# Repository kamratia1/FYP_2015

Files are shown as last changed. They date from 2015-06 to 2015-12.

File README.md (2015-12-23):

# Control of a MEMS Scanning Mirror for Display Applications
Imperial College London. Electrical and Electronic Engineering. 
Final Year Project. Kishan Amratia

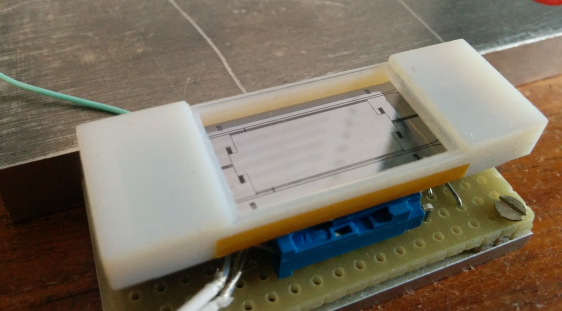
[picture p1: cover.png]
MEMS Scanning Mirror


The repository is split into different folders: 

* __MATLAB Files__: Contains all MATLAB scripts and files for the simulation model developed for the project
* __Microcontroller Files__: Contains software for the microcontroller
* __PCB Design Files__: Contains the EAGLE PCB designs and circuit schematics
* __PICOCAP Documents and Config__: Contains the software, documents and configuration files for the PICOCAP capacitance sensor chip
* __Video__: Contains slow motion video capture of the mirror (400fps)

Additional information on how to use these files is provided in the appendix of the final report

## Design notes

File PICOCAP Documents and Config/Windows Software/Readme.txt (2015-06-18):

INSTALLATION - README:
========================

1. Please do not connect the PicoProg programmer to the PC before asked by the software

2. Run setup.exe from the PCap02plus_Evaluation_and_Assembler

3. Step 2 usually installs the driver for the PicoProg. Only if this fails, please perform setup.exe from the Driver folder.

acam, 06.Feb.2014

========================
The lastest software can be donwloaded from:
http://www.acam.de/download-center/picocap/

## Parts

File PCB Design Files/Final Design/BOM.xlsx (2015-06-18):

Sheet: Digital
Part | Part Number | Description | Manufacturer | Supplier | Order Code | Qty | Unit Price (£)
U5 | STM32F030F4P6TR | ARM Cortex M0 Microcontroller | ST Microelectronics | Farnell | 2432084 | 1 | 0.878
J2, J3 | 22-28-4036 | 3 way 2.54mm pitch Header | MOLEX | Farnell | 1444318 | 2 | 0.06
J1, J4 | M52-040023V0545 | 1.27mm Pitch Stacking Board Connectors Header | HARWIN | Farnell | 1099560 | 2 | 0.406
X1, X2 | XF2M10151A | 10Way FPC Connector 0.5mm Pitch | OMRON | Farnell | 1112555 | 2 | 0.563
U4 | PCAP02AE | PICOCAP2 Digital Capacitance Sensor Chip | ACAM Messelectronic gmbh | SSL2001 | PCAP02AE | 1 | 8.64
U6 | MCP601T-I/OT | General Purpose Single Op-Amp | MICROCHIP | Farnell | 9758631 | 1 | 0.345

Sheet: Voltage Converter
Part | Part Number | Description | Manufacturer | Supplier | Order Code | Qty | Unit Price (£)
M1, M2 | BSS131 | N-Channel MOSFET, 100mA, 240V | Infineon | Farnell | 1056524 | 2 | 0.06
M5, M4 | IRLML2246TRPBF | P-Channel MOSFET, 2.6A, 20V | International Rectifier | Farnell | 1888166 | 2 | 0.0988
U1 | LT3468ES5 | Photoflash Cap Charger | Linear Technology | Farnell | 1663829 | 1 | 3.86
U3 | LM3480IM3-3.3/NOPB | Linear Regulator 3.3V, 100mA | Texas Instruments | Farnell | 1469102 | 1 | 1.2
T1 | CJ5143-ALB | Flyback Transformer 1:15, 15uH | Coilcraft | Farnell | 2458036 | 1 | 2.82
D3, D2 | B0540WS-7 | Schottky Rectifier 40V, 0.5A | Diodes Incorporated | Farnell | 1773477 | 2 | 0.2
D1 | MMBD3004S-7-F | 350V, 0.35W Series Diode Array (Min Order 25) | Diodes Incorporated | RS | 751-4492 | 1 | 0.12
C7, C10, C9, C11 | CGA9P3X7S2A156M250KB | SMD 2220 Package Ceramic Capacitor 100V, 15uF | TDK | Farnell | 2435508 | 4 | 1.3
U2 | LT1006S8 | Low Noise Operational Amplifier | Linear Technology | Farnell | 9559230 | 1 | 3.12
U7 | MCP601T-I/OT | General Purpose Single Op-Amp | MICROCHIP | Farnell | 9758631 | 1 | 0.345
J1, J2 | M52-5000545 | 1.27mm Pitch Stacking Board Connectors Socket | HARWIN | Farnell | 1099543 | 2 | 0.395
X1 | 353630260 | 2Way Right Angle Power Input Connector | MOLEX | Farnell | 9289437 | 1 | 0.0894
 | 355070200 | 2Way Power Input Connector Socket | MOLEX | Farnell | 7571550 | 1 | 0.0751
 | 502128100 | Molex Crimp | MOLEX | Farnell | 7571640 | 2 | 0.101

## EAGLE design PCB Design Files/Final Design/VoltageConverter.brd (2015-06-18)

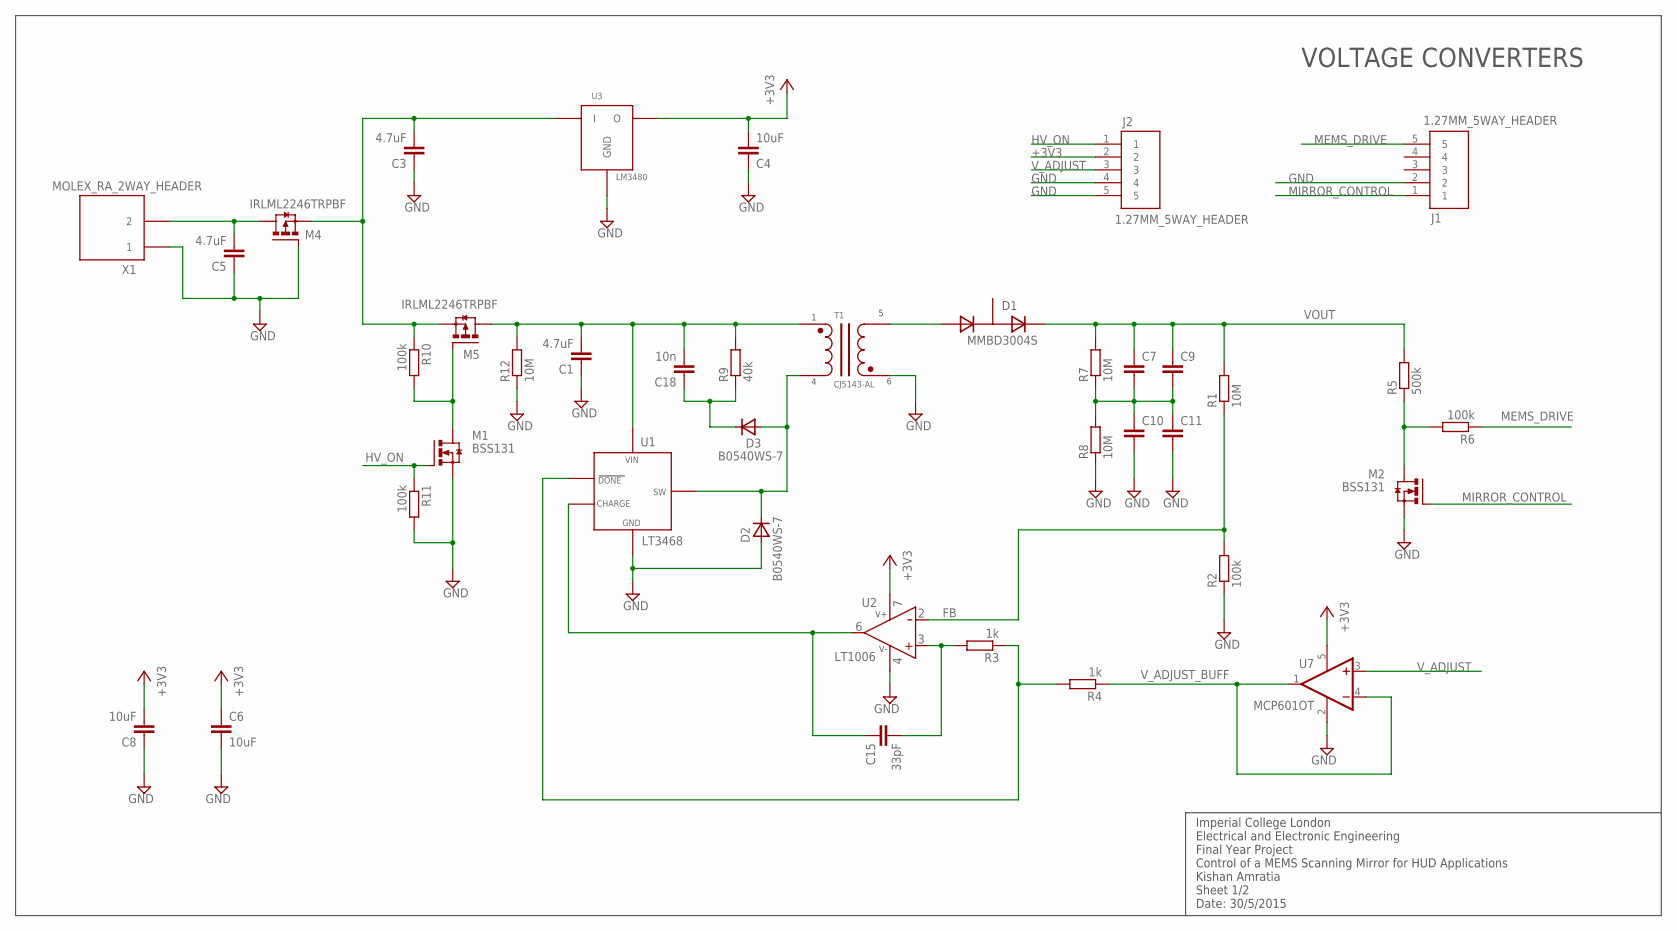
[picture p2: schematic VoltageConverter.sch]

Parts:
C1, C3, C5: 4.7uF; C0603K
C4, C6, C8: 10uF; C0603
C7, C9, C10, C11: C-EUC2220K; C2220K
C15: 33pF; C0603
C18: 10n; C0603K
D1: MMBD3004S; SOT-23
D2, D3: B0540WS-7; SOD-323
J1, J2: 1.27MM_5WAY_HEADER
M1, M2: BSS131; SOT-23
M4, M5: IRLML2246TRPBF; SOT-23
R1, R7, R8, R12: 10M; R0603
R2, R6, R10, R11: 100k; R0603
R3, R4: 1k; R0603
R5: 500k; R0603
R9: 40k; R0603
T1: CJ5143-AL; CJ45143-AL
U1: LT3468; TSOT-23
U2: LT1006; SOIC127P600X175-8N
U3: LM3480; SOT-23
U7: MCP601OT; SOT23-5
X1: MOLEX_RA_2WAY_HEADER

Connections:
+3V3: C4.2, C6.1, C8.2, J2.2, U2.7, U3.A (O), U7.5 (V+)
CHARGE: C15.1, U1.4, U2.6
DONE: R3.1, R4.2, U1.3
FB: R1.1, R2.2, U2.2
GND: C1.1, C3.1, C4.1, C5.1, C6.2, C8.1, C10.2, C11.2, D2.A, J1.2, J2.4, J2.5, M1.K (S), M2.K (S), M4.A (G), R2.1, R8.1, R11.2, R12.1, T1.5, U1.2, U2.4, U3.K1A2 (GND), U7.2 (V-), X1.P$1 (1)
HV_ON: J2.1, M1.A (G), R11.1
MEMS_DRIVE: J1.5, R6.1
MIRROR_CONTROL: J1.1, M2.A (G)
unnamed: C7.2, C9.2, C10.1, C11.1, R7.1, R8.2
unnamed: D1.A, T1.6
unnamed: C15.2, R3.2, U2.3
unnamed: M2.K1A2 (D), R5.1, R6.2
unnamed: M1.K1A2 (D), M5.A (G), R10.2
unnamed: C18.1, D3.K, R9.1
SW: D2.K, D3.A, T1.4, U1.1
VIN_LT3468: C1.2, C18.2, M5.K1A2 (D), R9.2, R12.2, T1.1, U1.5
VOUT: C7.1, C9.1, D1.K, R1.2, R5.2, R7.2
V_ADJUST: J2.3, U7.3 (+IN)
V_ADJUST_BUFF: R4.1, U7.1 (OUT), U7.4 (-IN)
V_IN: C5.2, M4.K1A2 (D), X1.P$2 (2)
V_IN2: C3.2, M4.K (S), M5.K (S), R10.1, U3.K (I)

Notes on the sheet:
Imperial College London Electrical and Electronic Engineering Final Year Project Control of a MEMS Scanning Mirror for HUD Applications Kishan Amratia Sheet 1/2 Date: 30/5/2015
VOLTAGE CONVERTERS

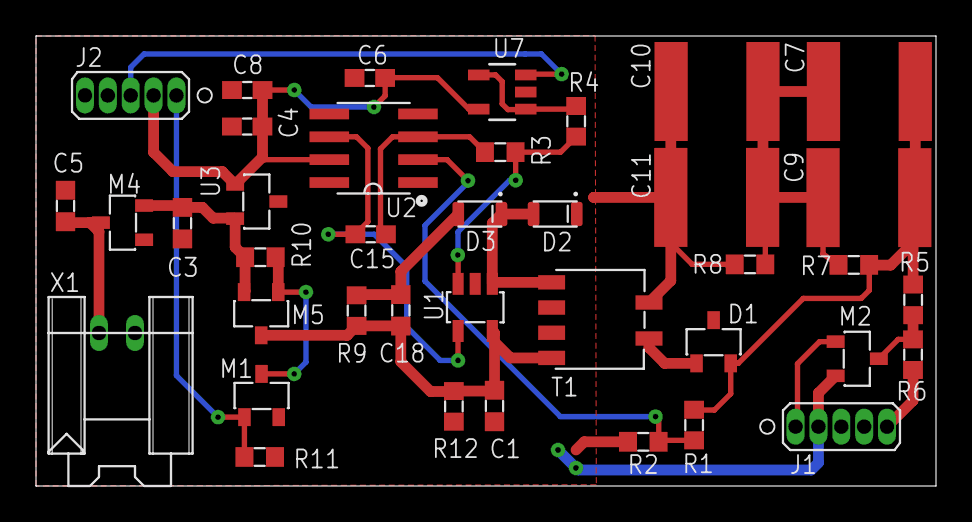
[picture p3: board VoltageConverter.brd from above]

Board: 2 copper layers, 50.0 x 25.0 mm, 39 parts (0 on the bottom side), 21 nets.

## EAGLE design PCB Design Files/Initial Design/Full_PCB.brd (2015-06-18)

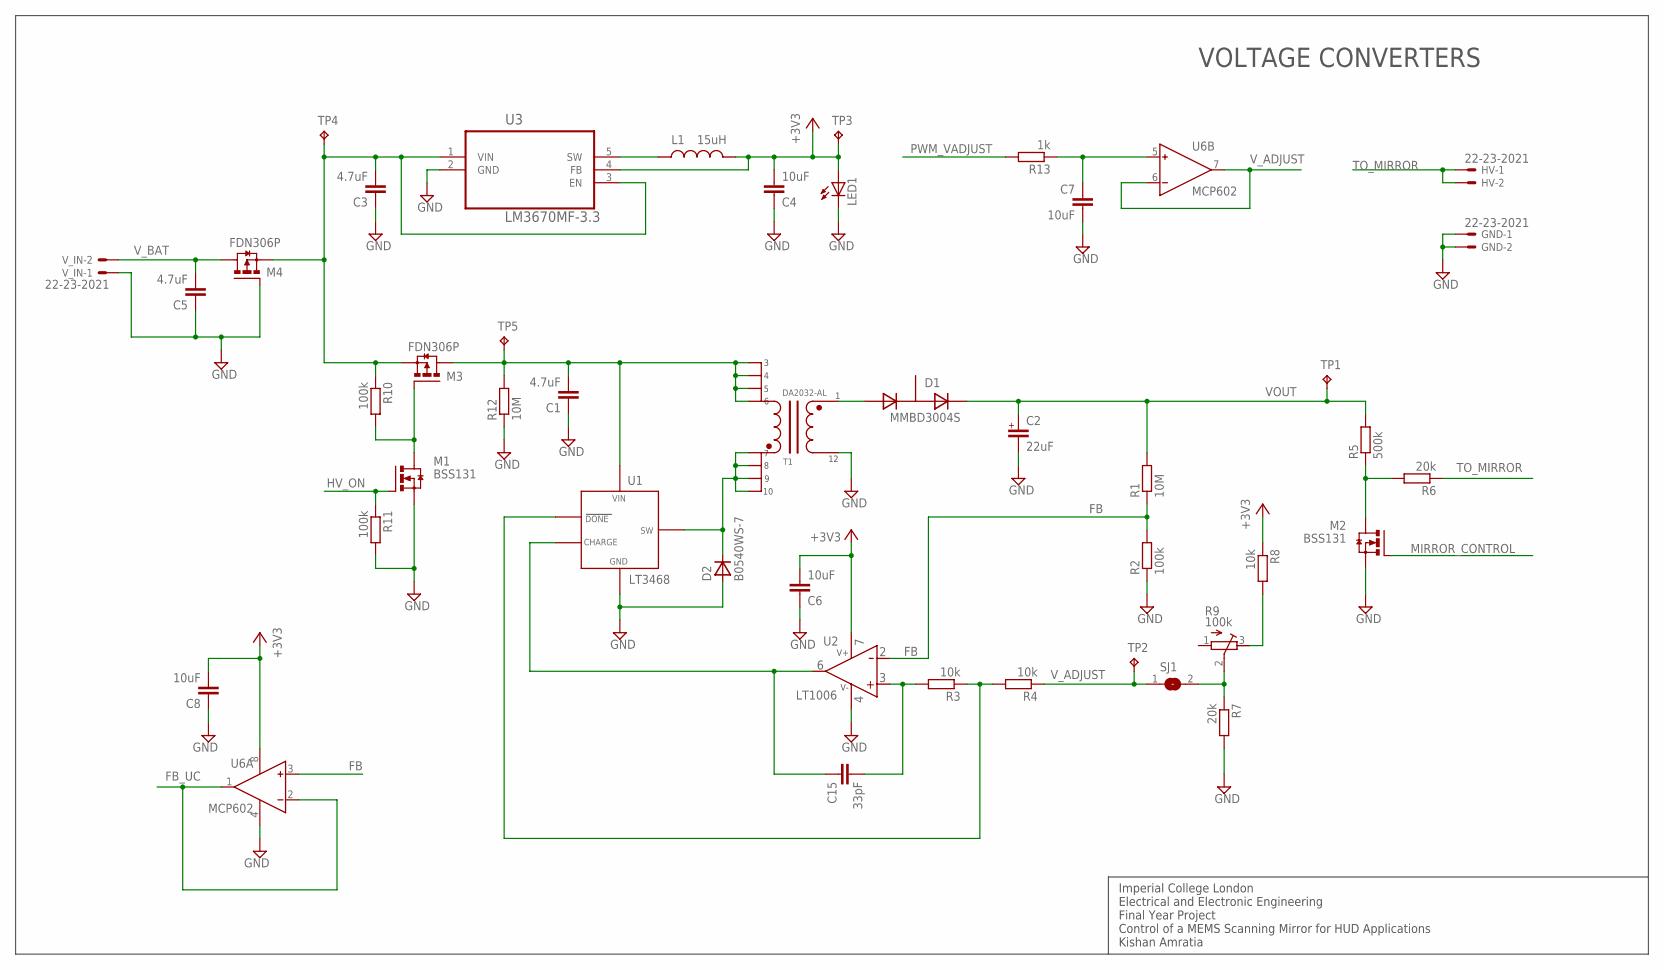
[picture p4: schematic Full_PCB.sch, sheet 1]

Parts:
C1, C3, C5: 4.7uF; C0603K
C2: 22uF; 5MM-RADIAL-LEAD
C4, C6, C7, C8: 10uF; C0603
C15: 33pF; C0603
D1: MMBD3004S; SOT-23
D2: B0540WS-7; SOD-323
GND: 22-23-2021
HV: 22-23-2021
L1: 15uH; IFSC1515AHER150M01
LED1: LEDCHIPLED_0603; CHIPLED_0603
M1, M2: BSS131; SOT-23
M3, M4: FDN306P; SSOT-3
R1, R12: 10M; R0603
R2, R10, R11: 100k; R0603
R3, R4, R8: 10k; R0603
R5: 500k; R1206
R6: 20k; R1206
R7: 20k; R0603
R9: 100k; TC33X-2-104E
R13: 1k; R0603
SJ1: SJ
T1: DA2032-AL
TP1, TP2, TP3, TP4, TP5: TPB1,27; B1,27
U1: LT3468; TSOT-23
U2: LT1006; SOIC127P600X175-8N
U3: LM3670MF-3.3; SOT95P284X122-5N
U6: MCP602; SOIC127P600X175-8N
V_IN: 22-23-2021

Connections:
+3V3: C4.2, C6.2, C8.2, L1.2, LED1.A, R8.1, TP3.TP, U2.7, U3.4 (FB), U6.8 (V+); also elsewhere on the board
FB: R1.1, R2.2, U2.2, U6.3 (IN+)
FB_UC: U6.1 (OUT), U6.2 (IN-); also elsewhere on the board
GND: C1.1, C2.2, C3.1, C4.1, C5.1, C6.1, C7.2, C8.1, D2.A, GND.1, GND.2, LED1.C, M1.K (S), M2.K (S), M4.1 (G), R2.1, R7.2, R11.2, R12.1, T1.12, U1.2, U2.4, U3.2 (GND), U6.4 (V-), V_IN.1; also elsewhere on the board
HV_ON: M1.A (G), R11.1; also elsewhere on the board
MIRROR_CONTROL: M2.A (G); also elsewhere on the board
unnamed: C7.1, R13.1, U6.5 (IN+)
unnamed: C15.1, U1.4, U2.6
unnamed: D1.A, T1.1
unnamed: R8.2, R9.3
unnamed: C1.2, M3.3 (D), R12.2, T1.3, T1.4, T1.5, T1.6, TP5.TP, U1.5
unnamed: R3.1, R4.2, U1.3
unnamed: C15.2, R3.2, U2.3
unnamed: M2.K1A2 (D), R5.1, R6.2
unnamed: R7.1, R9.2, SJ1.2
unnamed: D2.K, T1.7, T1.8, T1.9, T1.10, U1.1
unnamed: M1.K1A2 (D), M3.1 (G), R10.2
unnamed: L1.1, U3.5 (SW)
PWM_VADJUST: R13.2; also elsewhere on the board
TO_MIRROR: HV.1, HV.2, R6.1
VOUT: C2.1+, D1.K, R1.2, R5.2, TP1.TP
V_ADJUST: R4.1, SJ1.1, TP2.TP, U6.6 (IN-), U6.7 (OUT)
V_BAT: C5.2, M4.3 (D), V_IN.2
V_IN: C3.2, M3.2 (S), M4.2 (S), R10.1, TP4.TP, U3.1 (VIN), U3.3 (EN)

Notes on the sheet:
Imperial College London Electrical and Electronic Engineering Final Year Project Control of a MEMS Scanning Mirror for HUD Applications Kishan Amratia
VOLTAGE CONVERTERS

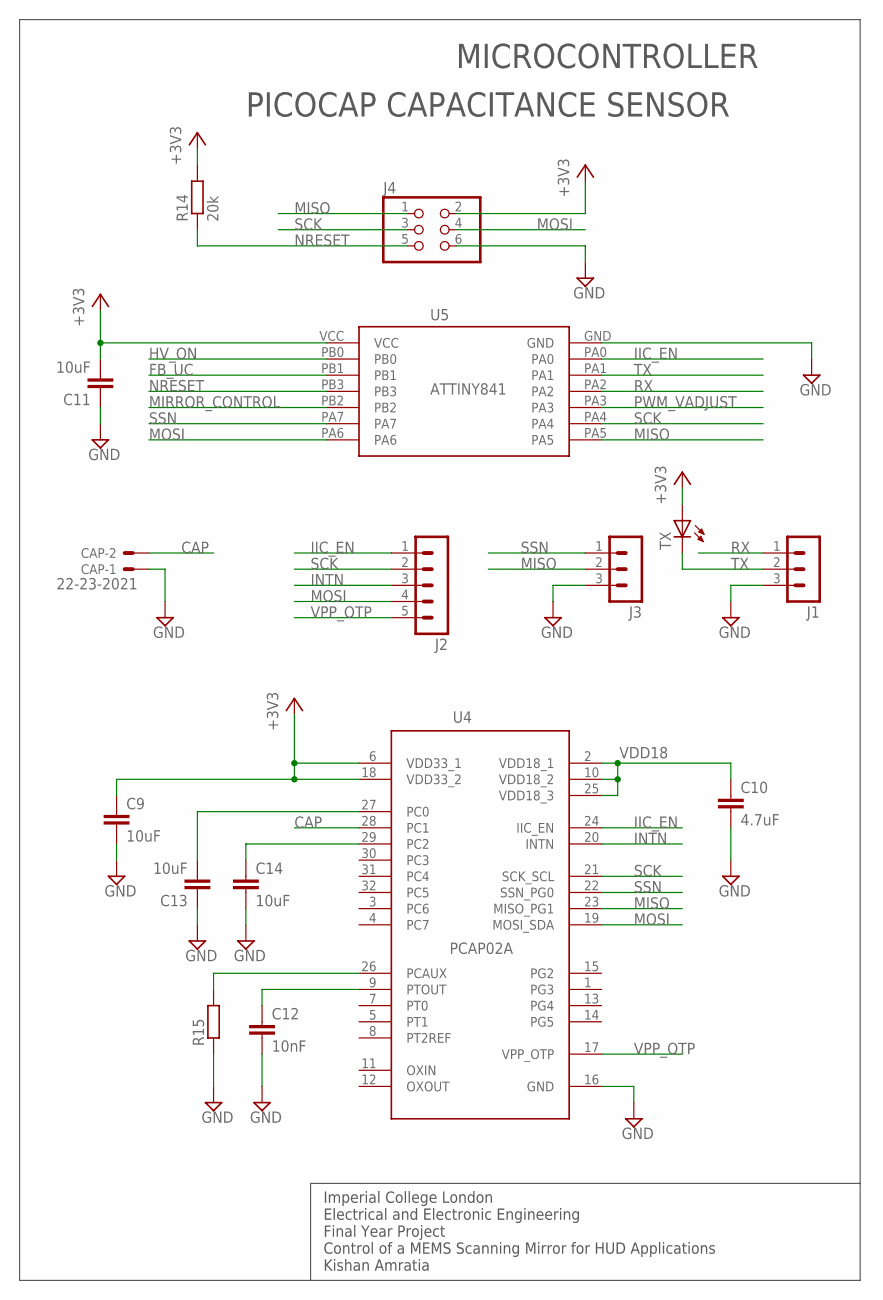
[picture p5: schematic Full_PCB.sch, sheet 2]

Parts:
C9, C11, C13, C14: 10uF; C0603K
C10: 4.7uF; C0603K
C12: 10nF; C0603K
CAP: 22-23-2021
J1, J3: MA03-1
J2: MA05-1
J4: PINHD-2X3; 2X03
R14: 20k; R0603
R15: R-EU_R0603; R0603
TX: LEDCHIPLED_0603; CHIPLED_0603
U4: PCAP02A; QFN32
U5: ATTINY841; SOIC-14

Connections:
+3V3: C9.1, C11.2, J4.2, R14.2, TX.A, U4.6 (VDD33_1), U4.18 (VDD33_2), U5.VCC; also elsewhere on the board
CAP: CAP.2, U4.28 (PC1)
FB_UC: U5.PB1; also elsewhere on the board
GND: C9.2, C10.2, C11.1, C12.2, C13.1, C14.2, CAP.1, J1.3, J3.3, J4.6, R15.1, U4.16 (GND), U5.GND; also elsewhere on the board
HV_ON: U5.PB0; also elsewhere on the board
IIC_EN: J2.1, U4.24 (IIC_EN), U5.PA0
INTN: J2.3, U4.20 (INTN)
MIRROR_CONTROL: U5.PB2; also elsewhere on the board
MISO: J3.2, J4.1, U4.23 (MISO_PG1), U5.PA5
MOSI: J2.4, J4.4, U4.19 (MOSI_SDA), U5.PA6
unnamed: C12.1, U4.9 (PTOUT)
unnamed: R15.2, U4.26 (PCAUX)
unnamed: C13.2, U4.27 (PC0)
unnamed: C14.1, U4.29 (PC2)
NRESET: J4.5, R14.1, U5.PB3
PWM_VADJUST: U5.PA3; also elsewhere on the board
RX: J1.1, U5.PA2
SCK: J2.2, J4.3, U4.21 (SCK_SCL), U5.PA4
SSN: J3.1, U4.22 (SSN_PG0), U5.PA7
TX: J1.2, TX.C, U5.PA1
VDD18: C10.1, U4.2 (VDD18_1), U4.10 (VDD18_2), U4.25 (VDD18_3)
VPP_OTP: J2.5, U4.17 (VPP_OTP)

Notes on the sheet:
Imperial College London Electrical and Electronic Engineering Final Year Project Control of a MEMS Scanning Mirror for HUD Applications Kishan Amratia
PICOCAP CAPACITANCE SENSOR
MICROCONTROLLER

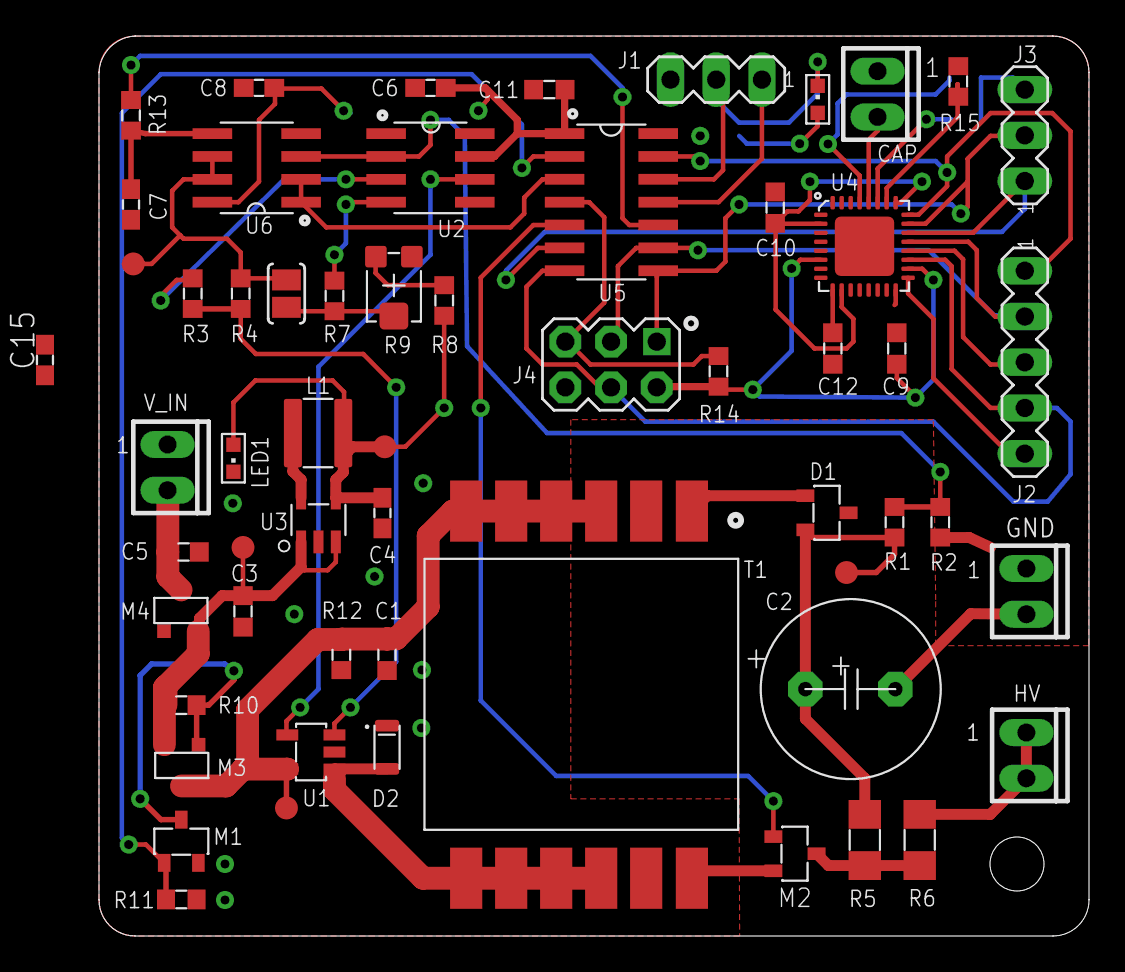
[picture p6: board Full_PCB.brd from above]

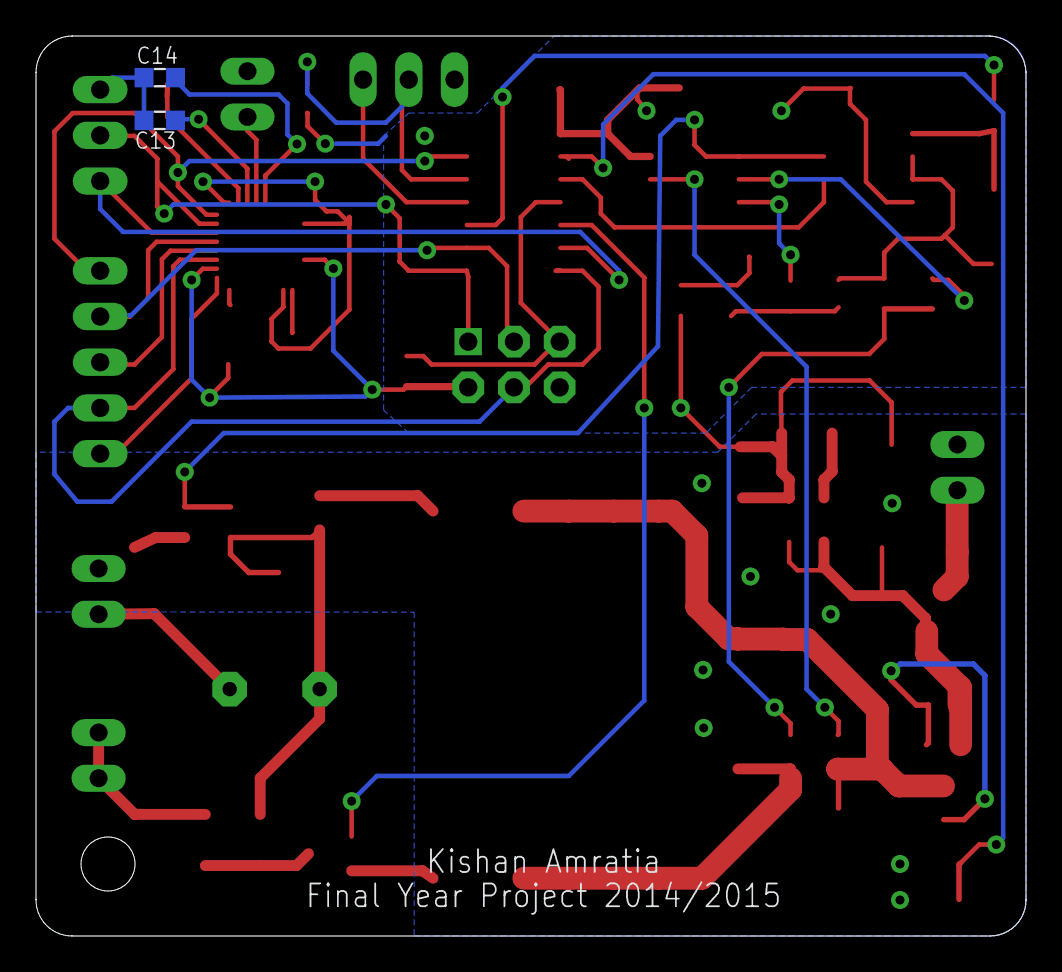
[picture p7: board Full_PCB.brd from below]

Board: 2 copper layers, 55.0 x 50.0 mm, 60 parts (2 on the bottom side), 40 nets.

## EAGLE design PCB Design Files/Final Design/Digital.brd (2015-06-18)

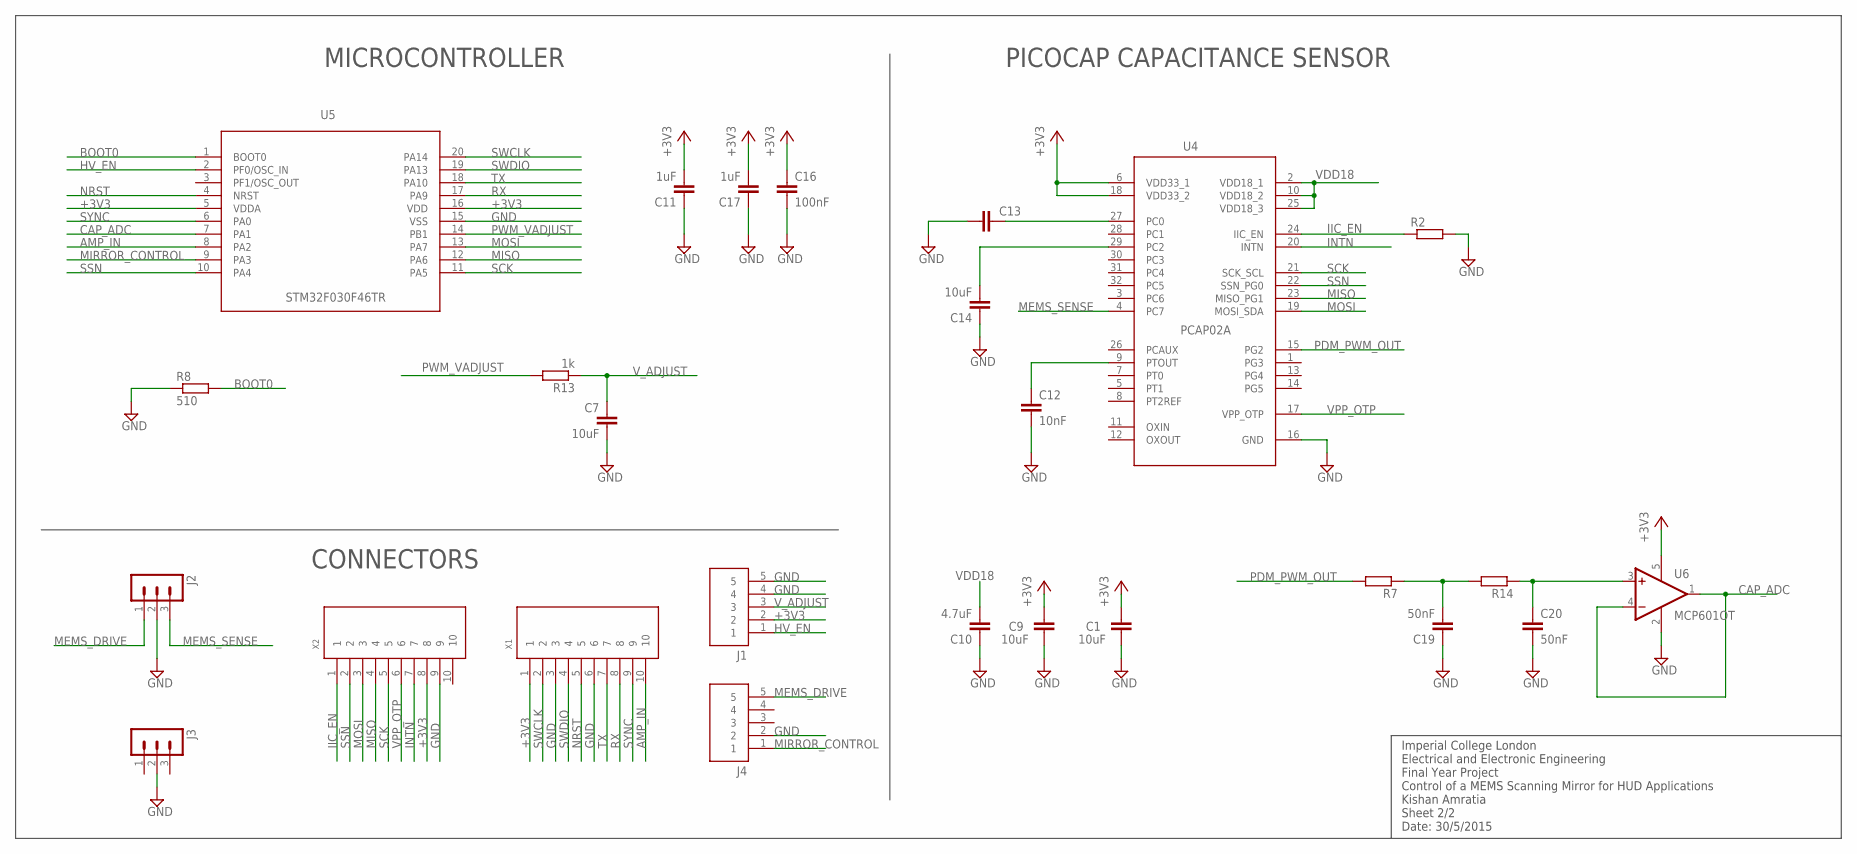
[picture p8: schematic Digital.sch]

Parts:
C1, C9, C14: 10uF; C0603K
C7: 10uF; C0603
C10: 4.7uF; C0603K
C11, C17: 1uF; C0603K
C12: 10nF; C0603K
C13: C-EUC0603K; C0603K
C16: 100nF; C0603K
C19, C20: 50nF; C0603K
J1, J4: 1.27MM_5WAY_HEADER
J2, J3: MA03-1
R2, R7, R14: R-EU_R0603; R0603
R8: 510; R0603
R13: 1k; R0603
U4: PCAP02A; QFN32
U5: STM32F030XX; TSOP20
U6: MCP601OT; SOT23-5
X1, X2: OMRON_FPC_0.5MM_10WAY

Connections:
+3V3: C1.1, C9.1, C11.2, C16.1, C17.2, J1.2, U4.6 (VDD33_1), U4.18 (VDD33_2), U5.5 (VDDA), U5.16 (VDD), U6.5 (V+), X1.1, X2.8
AMP_IN: U5.8 (PA2), X1.10
BOOT0: R8.2, U5.1 (BOOT0)
CAP_ADC: U5.7 (PA1), U6.1 (OUT), U6.4 (-IN)
GND: C1.2, C7.2, C9.2, C10.1, C11.1, C12.2, C13.1, C14.1, C16.2, C17.1, C19.1, C20.2, J1.4, J1.5, J2.2, J3.2, J4.2, R2.2, R8.1, U4.16 (GND), U5.15 (VSS), U6.2 (V-), X1.3, X1.6, X2.9
HV_EN: J1.1, U5.2 (PF0/OSC_IN)
IIC_EN: R2.1, U4.24 (IIC_EN), X2.1
INTN: U4.20 (INTN), X2.7
MEMS_DRIVE: J2.1, J4.5
MEMS_SENSE: J2.3, U4.4 (PC7)
MIRROR_CONTROL: J4.1, U5.9 (PA3)
MISO: U4.23 (MISO_PG1), U5.12 (PA6), X2.4
MOSI: U4.19 (MOSI_SDA), U5.13 (PA7), X2.3
unnamed: C19.2, R7.1, R14.2
unnamed: C12.1, U4.9 (PTOUT)
unnamed: C13.2, U4.27 (PC0)
unnamed: C14.2, U4.29 (PC2)
NRST: U5.4 (NRST), X1.5
PDM: C20.1, R14.1, U6.3 (+IN)
PDM_PWM_OUT: R7.2, U4.15 (PG2)
PWM_VADJUST: R13.2, U5.14 (PB1)
RX: U5.17 (PA9), X1.8
SCK: U4.21 (SCK_SCL), U5.11 (PA5), X2.5
SSN: U4.22 (SSN_PG0), U5.10 (PA4), X2.2
SWCLK: U5.20 (PA14), X1.2
SWDIO: U5.19 (PA13), X1.4
SYNC: U5.6 (PA0), X1.9
TX: U5.18 (PA10), X1.7
VDD18: C10.2, U4.2 (VDD18_1), U4.10 (VDD18_2), U4.25 (VDD18_3)
VPP_OTP: U4.17 (VPP_OTP), X2.6
V_ADJUST: C7.1, J1.3, R13.1

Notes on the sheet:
Imperial College London Electrical and Electronic Engineering Final Year Project Control of a MEMS Scanning Mirror for HUD Applications Kishan Amratia Sheet 2/2 Date: 30/5/2015
PICOCAP CAPACITANCE SENSOR
MICROCONTROLLER
CONNECTORS

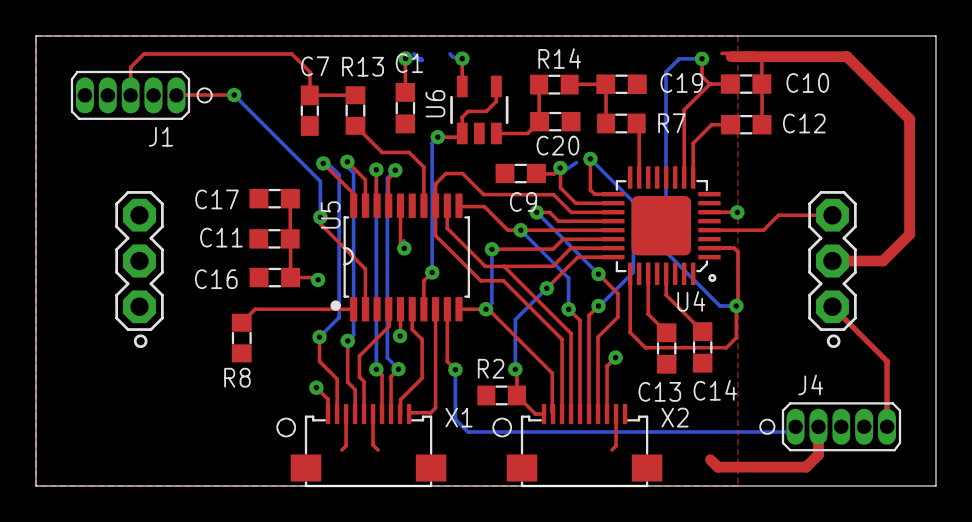
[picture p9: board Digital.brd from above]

Board: 2 copper layers, 50.0 x 25.0 mm, 26 parts (0 on the bottom side), 31 nets.

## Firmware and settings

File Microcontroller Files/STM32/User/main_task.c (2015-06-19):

#include "tasks.h"
#include "algorithm.h"

void drive_transition(void);

//Public Variables
U64 main_stk[MAIN_STK_SIZE];
OS_TID main_t;

uint32_t Counter;
uint8_t i = 0;

#define PHASE_DELAY 	3470  // in microseconds

__task void main_task(void)
{
	HV_ref_init(40000);			// Setup High Voltage Converter PWM frequency at 40kHz
	HV_set(HV_DEFAULT);			// Set HV Converter Duty cycle such that it outputs the default voltage set in config.h
	HV_en(1);								// Turn on HV_Converter
	
	os_dly_wait(50);				// wait for HV_Converter to settle
	
	startup_seq(50, 97, 25);	// Startup Sequence runs for 15 cycles, at 100 Hz Frequency and 25% duty cycle
	
	TIM3_Config(SAMP_FREQ);	// Setup 10kHz, sampling frequency
	
	while(1)
	{
		drive_transition();
	}

}

void drive_transition(void)
{
	// Function that determines the drive transistion i.e. rising or falling edge based on the capacitance derivative
	// Also takes care of phase delay
	if(drive_flg != 2)
		{
			TIM_ITConfig(TIM3, TIM_IT_CC3, DISABLE);	// Disable the Interrput timer
			
			if(drive_flg == 0)	// Set drive signal to 0
			{
				Counter = TIM_GetCounter(TIM2);					// Get counter value from timer2
				TIM_SetCounter(TIM2, 0);								// Reset the counter to zero
				
				delay_us(PHASE_DELAY);									// phase delay compensation
				mirror_drive_en(0);											// negative transition on drive signal
				SYNC_en(i);															// send out a synchronisation signal
				i = !i;
			}
			else 		// Set drive signal to 1
			{	
				delay_us(PHASE_DELAY);									// phase delay compensation
				mirror_drive_en(1);											// positive transistion of drive signal
			}
			
			TIM3_Config(SAMP_FREQ);		// Reset the interrupt timer
			drive_flg = 2;						// Reset the flag
		}	
}

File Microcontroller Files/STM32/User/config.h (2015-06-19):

#ifndef __config_h
#define __config_h

#include "stm32f0xx.h"
#include <RTL.h>
#include <stdio.h>

// Value definitions
#define HV_DEFAULT	50			// default value for High Voltage Converter
#define HV_LIMIT		160			// HV Converter Voltage limit
#define VCC					3.3			// Define VCC for determining the duty cycle for the HV Converter reference apprioprately

#define SAMP_FREQ		10000		// Define Sampling Frequency for the control algorithm

/* Pin Definitions */

// GPIOs
#define MIRROR_CONTROL_PIN			GPIO_Pin_8		// PC8	// In the final PCB this is PA3
#define MIRROR_CONTROL_PORT			GPIOC
#define MIRROR_CONTROL_CLK			RCC_AHBPeriph_GPIOC

#define HV_EN_PIN								GPIO_Pin_9		// PC9	// In the final PCB this is PF0
#define HV_EN_PORT							GPIOC
#define HV_EN_CLK								RCC_AHBPeriph_GPIOC

#define SYNC_PIN								GPIO_Pin_0		// PA0
#define SYNC_PORT								GPIOA
#define SYNC_CLK								RCC_AHBPeriph_GPIOA

// ADC for PICOCAP Capacitance Analogue Values
#define PCAP_PDM_PIN							GPIO_Pin_1		// PA1 
#define PCAP_PDM_PORT							GPIOA
#define PCAP_PDM_CLK							RCC_AHBPeriph_GPIOA
#define PCAP_ADC_SAMPLING_TIME		ADC_SampleTime_1_5Cycles
#define PCAP_PDM_ADC_CHANNEL			ADC_Channel_1 	

// PWM for HV Converter Voltage Adjust Definitions
#define PWM_VADJUST_PIN					GPIO_Pin_8		//PA8			// In the final PCB, this is PB1 on TIM1 Channel 3
#define PWM_VADJUST_PORT				GPIOA
#define PWM_VADJUST_CLK					RCC_AHBPeriph_GPIOA
#define PWM_VADJUST_AF_PIN			GPIO_PinSource8		
#define PWM_VADJUST_AF					GPIO_AF_2					
#define PWM_TIMER_CLK						RCC_APB2Periph_TIM1		
#define PWM_TIMER								TIM1							

// UART pin definitions can be found in serial.h

//#define DEBUG	// Defines TRACE level

#ifdef DEBUG
	#define USE_FULL_ASSERT
	#warning "Using Debug mode, for production do not use debug mode"
	#define TRACE_LEVEL TRACE_LEVEL_DEBUG
#else
	#define TRACE_LEVEL TRACE_LEVEL_INFO
#endif

#include "trace.h"

#endif

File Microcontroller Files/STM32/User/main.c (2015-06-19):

#include "config.h"
#include "serial.h"
#include "tasks.h"

__task void init(void)
{	
	// Setup the different tasks for the RTOS
	
	// Main Task: Runs the algorithm for controlling the mirror
	main_t = os_tsk_create_user(main_task, 0, &main_stk, sizeof(main_stk));	
	
	// Auxillary Task: sends and recevies data to/from PC to set variables in the software
	aux_t = os_tsk_create_user(aux_task, 1, &aux_stk, sizeof(aux_stk));
	
	/* os_tsk_delete_self:
		 Function stops and deletes the currently running task. The function doesnt return.
		 The program execution continues with the task with the next highest priority in the ready queue. 
	*/
	os_tsk_delete_self ();
}


int main(void)
{
	Serial.begin(115200);		// Initialise serial interface at 115200 baud rate
	IO_init();							// Initialise all I/O pins
	ADC_init();							// Initialise ADC for capacitance measurement						
	TIM2_Config();					// Setup Timer2 as a counter for time measurement purposes

	os_sys_init(init); 
	
  while(1);
	
}


#ifdef  USE_FULL_ASSERT

/**
  * @brief  Reports the name of the source file and the source line number
  *         where the assert_param error has occurred.
  * @param  file: pointer to the source file name
  * @param  line: assert_param error line source number
  * @retval None
  */
void assert_failed(uint8_t* file, uint32_t line)
{
  /* User can add his own implementation to report the file name and line number,
     ex: printf("Wrong parameters value: file %s on line %d\r\n", file, line) */
	//
	//TRACE_FATAL("Wrong parameters value: file %s on line %d\n", file, line);

  /* Infinite loop */
  while (1)
  {
  }
}
#endif

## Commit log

2015-06-18 Added PCB Design Files
    [BOM.xlsx, Digital.brd, Digital.sch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]
2015-06-18 Added STM32 Code
2015-06-18 Added config and firmware files for PICOCAP
    [config.cfg, standard_firmware.cfg]
2015-06-19 Edited Config File
    [config.cfg]
2015-06-19 Added Some extra Comments for pin config
